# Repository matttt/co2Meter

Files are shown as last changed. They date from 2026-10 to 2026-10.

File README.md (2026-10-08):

# ESP32-C6 eInk CO2 meter

IMG_9852 Medium

IMG_9853 Medium

CleanShot 2026-10-07 at 20 32 52

built with:
- [ESP32-C6 Feather, product 5933](https://www.adafruit.com/product/5933)
- [2.13-inch 250x122 monochrome eInk breakout, product 4197](https://www.adafruit.com/product/4197)
- [SCD-40 CO2, temperature, and humidity sensor, product 5187](https://www.adafruit.com/product/5187)
- Small lipo battery ~1000mAH, ~20x40mm in the major dimensions
- some M2 heat set inserts and M2 x 6mm socket head screws

The following is LLM generated, apologies for the verbosity, but there's some useful stuff:

At boot and after each wake, the firmware starts the SCD-40's low-power
periodic mode, reads one valid sample after about 30 seconds, stops measurement,
and renders the dashboard. The ESP32 then deep sleeps for one hour and repeats.
There is no five-minute sampling or averaging. The eInk image remains visible
while asleep; flashing during its several-second refresh is normal.

Solder the supplied header onto the eInk breakout before making these jumper
connections.

## Wiring

Use the breakout's header pins. The first column uses labels printed on the
Feather; the GPIO column is included to remove any ambiguity.

| ESP32-C6 Feather | GPIO | eInk breakout |
| --- | ---: | --- |
| `3V` | - | `VIN` / `3-5V` |
| `GND` | - | `GND` |
| `SCK` | 21 | `SCK` / `CLK` |
| `MO` / `MOSI` | 22 | `MOSI` |
| `MI` / `MISO` | 23 | `MISO` |
| `0` / `SS` | 0 | `ECS` |
| `A0` | 1 | `D/C` |
| `A5` | 2 | `SRCS` |
| `A4` | 3 | `RST` |
| `A2` | 6 | `ENA` |
| `7` | 7 | `BUSY` |
| `TX` | 16 | `SDCS` |

Leave the display's `3.3V out` pin disconnected. Be careful to use the
display's `VIN` input, not its `3.3V out` regulator output, for power.

This mapping uses the Feather's hardware SPI pins; avoids the C6 strapping,
USB-JTAG, boot/NeoPixel, and LED pins; and leaves I2C/STEMMA QT available for
the SCD-40. GPIO 16 is reserved for SD chip select, so it is no longer available
as hardware UART TX.

## SCD-40 connection

The easiest connection is a STEMMA QT cable between the Feather and SCD-40. No
additional display pins are shared. For individual wires, use:

| SCD-40 | ESP32-C6 Feather | GPIO |
| --- | --- | ---: |
| `VIN` | `3V` | - |
| `GND` | `GND` | - |
| `SCL` | `SCL` | 18 |
| `SDA` | `SDA` | 19 |

The firmware displays temperature in Fahrenheit by default. Set
`kUseFahrenheit` to `false` in `src/main.cpp` to display Celsius.

## Battery warnings

The Feather's onboard MAX17048 fuel gauge shares I2C with the SCD-40; no extra
wiring is required. The firmware checks it on each wake, while waiting for a
sensor sample, and before displaying a reading or sensor error. At **20% or
less**, a small low-battery icon appears in the top-left corner of the dashboard
and sensor-error screen.

At **5% or less**, or a cell voltage of **3.4 V or less**, the dashboard is
replaced by a full-screen empty-battery icon, **LOW BATTERY**, and **PLEASE
RECHARGE**. The firmware skips sensor measurements and deep sleeps, checking
again at the next wake so readings resume after recharging. This reserves charge
for the final refresh: eInk retains the warning after power is lost, but cannot
draw a new image once power has already cut out, including during sleep.

Tune `kLowBatteryPercent`, `kDepletedBatteryPercent`, and
`kDepletedBatteryVoltage` in `src/main.cpp` for your battery. Missing batteries
and failed gauge reads do not count as depletion; the firmware retains the last
valid state for that wake, or starts without a warning when none is available.
The gauge is read without resetting its charge estimate on each wake.

## Deep sleep and interval tuning

Set `kSleepIntervalMinutes` near the top of `src/main.cpp`: `60` for one hour,
`120` for two hours. This is the sleep duration **after** each refresh, so the
interval between displayed readings also includes measurement and refresh time.
For a quick hardware check, temporarily set it to `1`.

The SCD-40 uses a start/read/stop sequence because it does not support true
single-shot CO2 measurement. Before host sleep, the firmware releases I2C and
its internal pull-ups, then drives GPIO20 (`PIN_NEOPIXEL_I2C_POWER`) low and
holds it there. This switches off the STEMMA QT supply, including the SCD-40
and its green power LED, without extra wiring. On wake, power is restored and
the firmware waits one second before initializing the sensor. This also powers
off any other devices on that STEMMA supply and the onboard NeoPixel.

This power switching requires the sensor to be powered through STEMMA QT;
a sensor wired directly to the Feather's `3V` pin stays powered.
See [Adafruit's low-power guide](https://learn.adafruit.com/adafruit-esp32-c6-feather/low-power-use).

A failed initialization or a measurement that produces no valid reading within
45 seconds displays a sensor error and sleeps before retrying next wake.

The display library sleeps the panel controller after refreshing. The firmware
holds `ENA` high during ESP32 deep sleep to keep the display/SRAM rail powered
and avoid back-powering it through control pins. It also retains SD deselection. This is ESP32 deep sleep, not a complete peripheral power
shutdown; total board current still needs to be measured on hardware.

## BOOT button programming mode

**Add a jumper from Feather `IO9` to `A3` (GPIO 5).** BOOT is connected to GPIO 9,
which cannot wake the ESP32-C6 from deep sleep. GPIO 5 is an unused wake-capable
input; the jumper lets the same button drive it. Both pins are configured as
inputs with pull-ups. Do not drive the onboard NeoPixel while using this jumper,
since it shares GPIO 9.

Press BOOT to wake immediately, and keep holding for ten seconds after firmware
starts to enter programming mode. The screen displays **PROGRAMMING MODE**, and
the firmware stays awake indefinitely for uploading. Release BOOT once that
message appears. Tap RESET with BOOT released to resume normal operation.
A shorter press wakes the meter for a normal reading and starts a new sleep
interval. Holding BOOT while already awake also enters programming mode.

Without the jumper, BOOT can enter programming mode only while the firmware is
already awake. To access it while sleeping, tap RESET first, then press and hold
BOOT once firmware starts. Holding BOOT *during reset* selects the ROM bootloader
instead; that remains an alternative recovery/upload path but cannot render the
programming-mode screen.

The ten-second hold is checked in firmware after wake, since the hardware wake
source triggers on a low level rather than timing the press. Allow additional
time for startup and the eInk refresh before the message appears. Programming
mode lasts until reset or power cycling; it is not saved in flash.

The microSD card shares `SCK`, `MOSI`, and `MISO` with the display and SRAM. Its
separate `SDCS` connection uses `TX` / GPIO 16. Until SD support is added, the
firmware holds this pin high to keep the card deselected. USB serial remains
available, but GPIO 16 should no longer be used as a hardware UART TX pin.

## Build and upload

From this directory:

```sh
pio run
pio run --target upload
pio device monitor
```

The serial monitor runs at 115200 baud. If PlatformIO cannot enter the ROM
bootloader automatically, hold **BOOT**, tap **RESET**, release **BOOT**, and run
the upload command again.

## Display revision

This particular display's ribbon is marked `FPC-7528B`, so the firmware uses
the `ThinkInk_213_Mono_BN` SSD1680 driver. Its framebuffer needs an 8-pixel
memory offset; using `ThinkInk_213_Mono_GDEY0213B74` causes a shifted image and
a noisy strip along one edge.

For a different panel, select its driver by its physical marking:

- `GDEY0213B74` / `FPC-A002`: use `ThinkInk_213_Mono_GDEY0213B74`.
- Very old SSD1675 product 4197 units: use `ThinkInk_213_Mono_B72`. The SSD1675
  and SSD1680 are not code-compatible.

Adafruit references:

- [eInk breakout pinout](https://learn.adafruit.com/adafruit-2-13-eink-display-breakouts-and-featherwings/pinouts)
- [ESP32-C6 Feather pinout](https://learn.adafruit.com/adafruit-esp32-c6-feather/pinouts)
- [Adafruit EPD Arduino library](https://github.com/adafruit/Adafruit_EPD)
- [Adafruit SCD-4x Arduino guide](https://learn.adafruit.com/adafruit-scd-40-and-scd-41/arduino)
- [Sensirion SCD4x Arduino library](https://github.com/Sensirion/arduino-i2c-scd4x)

## Hardware verification

- With a one-minute test interval, confirm one reading after about 30 seconds,
  followed by a sleep log, USB disconnect, timer wake, and a fresh reading.
  Confirm the SCD-40 green LED is off throughout sleep and lights again on wake.
- With IO9 jumpered to A3, hold BOOT during sleep until PROGRAMMING MODE appears.
  Release it, wait longer than the test interval, and confirm USB remains usable
  and the screen remains in programming mode. Upload, or RESET to resume.
- Try a short BOOT press during sleep: it should take a normal reading and sleep.
- Disconnect the sensor: confirm the error screen and a subsequent sleep/retry.
- Check with a low battery: confirm the corner icon at 20% or less. At 5% or
  less or 3.4 V or less, confirm the full-screen warning and sleep without an
  SCD-40 measurement. Recharge and wake/reset to confirm readings resume. For a
  quick screen check, temporarily raise the percentage thresholds above the
  charge reported in the serial log, then restore them before normal use.
- With only USB power and no battery, confirm the dashboard still renders.
- Restore the intended interval before the final upload.

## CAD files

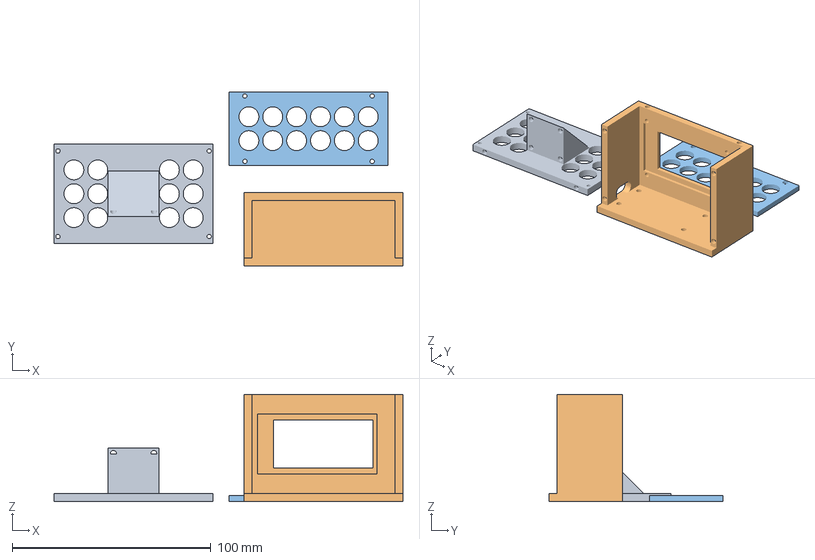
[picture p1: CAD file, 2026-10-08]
3dPrintFiles/co2 case.3mf
175.5 x 87.4 x 54.0 mm
back panel.obj
bodyody.obj
top.obj

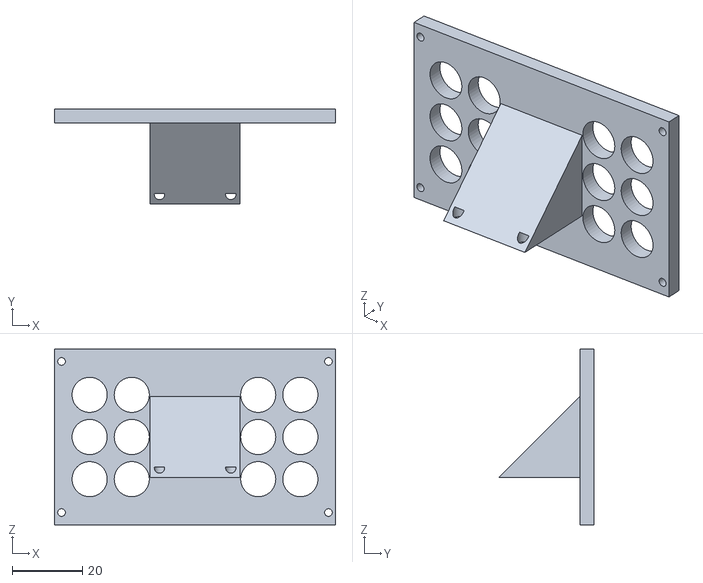
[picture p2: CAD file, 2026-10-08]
3dPrintFiles/back panel.obj
80.0 x 27.0 x 50.0

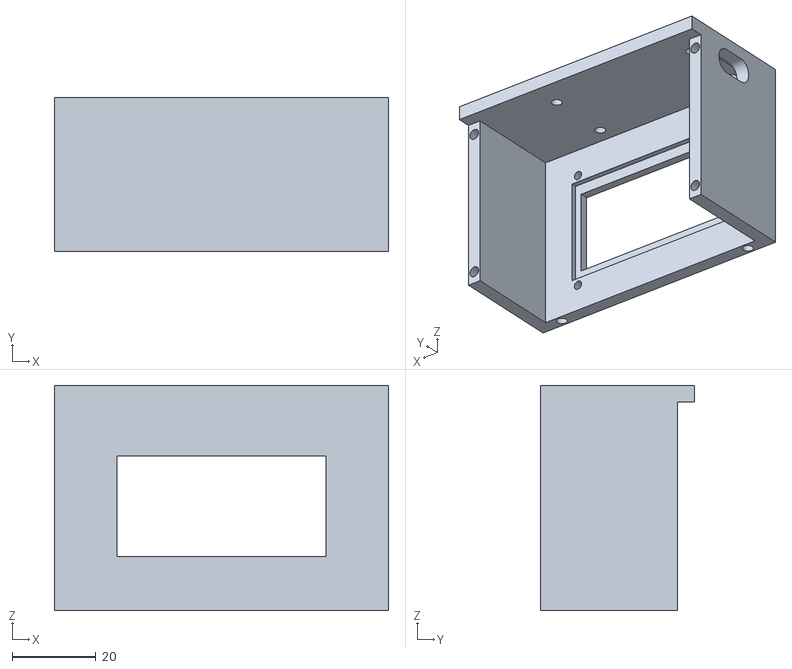
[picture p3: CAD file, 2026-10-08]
3dPrintFiles/bodyody.obj
80.0 x 36.9 x 54.0

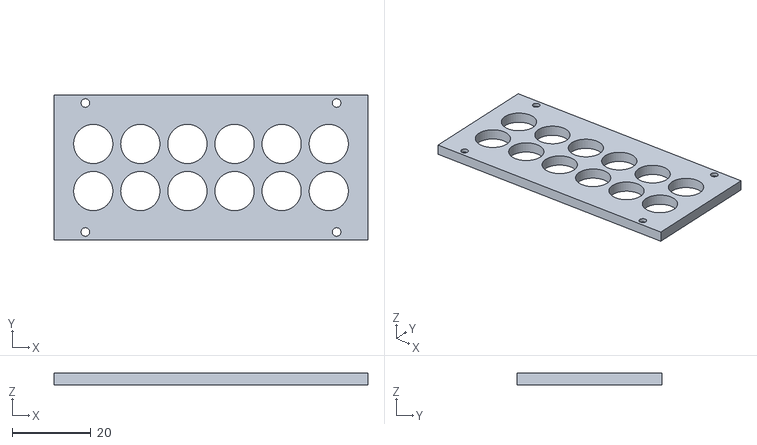
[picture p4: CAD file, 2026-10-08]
3dPrintFiles/top.obj
80.0 x 36.9 x 3.00

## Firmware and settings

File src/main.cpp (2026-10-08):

#include <Arduino.h>
#include <Adafruit_ThinkInk.h>
#include <Fonts/FreeSansBold24pt7b.h>
#include <Fonts/FreeSansBold9pt7b.h>
#include <SensirionI2cScd4x.h>
#include <Wire.h>
#include <driver/gpio.h>
#include <esp_sleep.h>

namespace {

// Adafruit ESP32-C6 Feather -> Adafruit 2.13" eInk breakout wiring.
// The display, SRAM, and microSD card share the Feather's hardware SPI bus.
constexpr int8_t kEpdCs = SS;      // GPIO 0 -> ECS
constexpr int8_t kEpdDc = A0;      // GPIO 1 -> D/C
constexpr int8_t kSramCs = A5;     // GPIO 2 -> SRCS
constexpr int8_t kEpdReset = A4;   // GPIO 3 -> RST
constexpr int8_t kEpdBusy = 7;     // GPIO 7 -> BUSY
constexpr int8_t kEpdEnable = A2;  // GPIO 6 -> ENA (HIGH = powered)
constexpr int8_t kSdCs = TX;       // GPIO 16 -> SDCS (LOW = selected)

// Sleep duration AFTER each measurement and display refresh. Change to 120
// for two hours; use a short interval when testing on hardware.
constexpr uint32_t kSleepIntervalMinutes = 60;
constexpr uint64_t kSleepIntervalUs =
    static_cast<uint64_t>(kSleepIntervalMinutes) * 60ULL * 1000000ULL;
constexpr uint32_t kSensorPollIntervalMs = 1000;
constexpr uint32_t kMeasurementTimeoutMs = 45UL * 1000UL;
constexpr uint32_t kDisplayPowerUpDelayMs = 100;
constexpr uint32_t kSensorPowerUpDelayMs = 1000;
constexpr uint32_t kProgrammingHoldMs = 10UL * 1000UL;
constexpr int8_t kBootButton = 9;
// REQUIRED jumper: IO9 -> A3. GPIO9 cannot wake the C6 from deep sleep.
constexpr gpio_num_t kWakeButton = GPIO_NUM_5;
constexpr int16_t kLayoutOffsetX = -4;
constexpr int16_t kSidebarContentOffsetX = 3;
constexpr bool kUseFahrenheit = true;
constexpr int16_t kNoError = 0;
// The onboard MAX17048 shares I2C with the SCD-40. Leave enough charge for a
// final eInk refresh before the battery or regulator cuts off power.
constexpr uint8_t kBatteryMonitorAddress = 0x36;
constexpr float kLowBatteryPercent = 20.0F;
constexpr float kDepletedBatteryPercent = 5.0F;
constexpr float kDepletedBatteryVoltage = 3.4F;

static_assert(kSleepIntervalMinutes > 0);
static_assert(kDepletedBatteryPercent < kLowBatteryPercent);

// This display is marked FPC-7528B. Its SSD1680 framebuffer needs the BN/B74
// memory offset; using the GDEY0213B74 driver leaves a noisy 8-pixel strip.
ThinkInk_213_Mono_BN display(kEpdDc, kEpdReset, kEpdCs, kSramCs, kEpdBusy,
                             &SPI);
SensirionI2cScd4x scd40;

struct AirReading {
  uint16_t co2Ppm;
  float temperatureC;
  float humidityPercent;
};

enum class BatteryState { Unknown, Normal, Low, Depleted };

BatteryState batteryState = BatteryState::Unknown;
bool sensorAvailable = false;
bool measurementRunning = false;
bool programmingMode = false;
uint32_t lastSensorPollMs = 0;
uint32_t measurementStartedMs = 0;

bool readBatteryRegister(uint8_t address, uint16_t& value) {
  Wire.beginTransmission(kBatteryMonitorAddress);
  Wire.write(address);
  if (Wire.endTransmission(false) != 0) {
    return false;
  }
  if (Wire.requestFrom(kBatteryMonitorAddress, static_cast<size_t>(2)) != 2) {
    return false;
  }
  value = static_cast<uint16_t>(Wire.read()) << 8;
  value |= static_cast<uint16_t>(Wire.read());
  return true;
}

void updateBatteryStatus(bool logReading = false) {
  uint16_t version = 0;
  uint16_t rawVoltage = 0;
  uint16_t rawPercent = 0;
  // Read without resetting/quick-starting the gauge on each deep-sleep wake;
  // its state-of-charge estimate must continue tracking while the ESP32 sleeps.
  // An absent battery or I2C failure must not be mistaken for an empty battery.
  if (!readBatteryRegister(0x08, version) ||
      (version & 0xFFF0) != 0x0010 ||
      !readBatteryRegister(0x02, rawVoltage) ||
      !readBatteryRegister(0x04, rawPercent) || rawVoltage == 0 ||
      rawPercent == 0xFFFF) {
    if (logReading) {
      Serial.println("Battery reading unavailable; retaining last known state.");
    }
    return;
  }

  // MAX17048 VCELL is 78.125 uV/LSB; SOC is 1/256 percent/LSB.
  const float voltage = rawVoltage * 0.000078125F;
  const float percent = min(rawPercent / 256.0F, 100.0F);
  if (voltage > 4.5F) {
    return;
  }
  if (percent <= kDepletedBatteryPercent ||
      voltage <= kDepletedBatteryVoltage) {
    batteryState = BatteryState::Depleted;
  } else if (percent <= kLowBatteryPercent) {
    batteryState = BatteryState::Low;
  } else {
    batteryState = BatteryState::Normal;
  }
  if (logReading) {
    Serial.printf("Battery: %.1f%%, %.3f V\n", percent, voltage);
  }
}

void printSensorError(const char* operation, int16_t error) {
  char message[64] = {};
  errorToString(error, message, sizeof(message));
  Serial.printf("SCD-40 %s failed: %s (error %d)\n", operation, message,
                error);
}

void initializeDisplay() {
  // Keep the breakout rail powered; display.display() puts the panel controller
  // into sleep after refreshing. Reinitialize after each ESP32 deep-sleep wake.
  pinMode(kEpdEnable, OUTPUT);
  digitalWrite(kEpdEnable, HIGH);
  delay(kDisplayPowerUpDelayMs);

  display.begin(THINKINK_MONO);
  display.setRotation(2);
  display.setTextColor(EPD_BLACK);
  display.setTextWrap(false);
}

void finishDisplayUpdate() {
  Serial.println("Refreshing eInk display...");
  const uint32_t refreshStartedMs = millis();
  display.display();
  Serial.printf("eInk refresh complete in %lu ms; panel controller asleep.\n",
                static_cast<unsigned long>(millis() - refreshStartedMs));
}

void drawCenteredText(const char* text, int16_t centerX, int16_t baselineY,
                      const GFXfont* font) {
  int16_t x1 = 0;
  int16_t y1 = 0;
  uint16_t width = 0;
  uint16_t height = 0;

  display.setFont(font);
  display.getTextBounds(text, 0, baselineY, &x1, &y1, &width, &height);
  display.setCursor(centerX - static_cast<int16_t>(width) / 2 - x1,
                    baselineY);
  display.print(text);
}

void drawBatteryIcon(int16_t x, int16_t y, uint8_t scale, bool empty) {
  display.drawRect(x, y, 20 * scale, 12 * scale, EPD_BLACK);
  display.drawRect(x + scale, y + scale, 18 * scale, 10 * scale,
                   EPD_BLACK);
  display.fillRect(x + 20 * scale, y + 4 * scale, 2 * scale, 4 * scale,
                   EPD_BLACK);
  if (!empty) {
    display.fillRect(x + 3 * scale, y + 3 * scale, 3 * scale, 6 * scale,
                     EPD_BLACK);
  }
}

void drawLowBatteryWarning() {
  if (batteryState == BatteryState::Low) {
    drawBatteryIcon(4, 4, 1, false);
  }
}

void showDepletedBattery() {
  display.clearBuffer();
  display.setTextSize(1);
  const int16_t centerX = display.width() / 2 + kLayoutOffsetX;
  drawBatteryIcon(centerX - 33, 18, 3, true);
  drawCenteredText("LOW BATTERY", centerX, 80, &FreeSansBold9pt7b);
  drawCenteredText("PLEASE RECHARGE", centerX, 104, nullptr);
  finishDisplayUpdate();
}

void drawCo2Value(uint16_t co2Ppm) {
  char value[8] = {};
  snprintf(value, sizeof(value), "%u", co2Ppm);

  // A three-digit value uses the 24pt font at 2x scale. Step down to its native
  // size at four digits so both cases remain large without touching the rule.
  constexpr GFXfont const* kValueFont = &FreeSansBold24pt7b;
  const uint8_t valueScale = co2Ppm < 1000 ? 2 : 1;

  int16_t valueX1 = 0;
  int16_t valueY1 = 0;
  int16_t ppmX1 = 0;
  int16_t ppmY1 = 0;
  int16_t co2X1 = 0;
  int16_t co2Y1 = 0;
  uint16_t valueWidth = 0;
  uint16_t valueHeight = 0;
  uint16_t ppmWidth = 0;
  uint16_t ppmHeight = 0;
  uint16_t co2Width = 0;
  uint16_t co2Height = 0;

  display.setFont(kValueFont);
  display.setTextSize(valueScale);
  display.getTextBounds(value, 0, 0, &valueX1, &valueY1, &valueWidth,
                        &valueHeight);
  display.setFont(nullptr);
  display.setTextSize(1);
  display.getTextBounds("PPM", 0, 0, &ppmX1, &ppmY1, &ppmWidth, &ppmHeight);
  display.getTextBounds("CO2", 0, 0, &co2X1, &co2Y1, &co2Width, &co2Height);

  constexpr int16_t kLabelGap = 7;
  const int16_t sidebarLeft =
      display.width() * 3 / 4 + kLayoutOffsetX;
  const int16_t co2AreaCenterX = (kLayoutOffsetX + sidebarLeft) / 2;
  const int16_t labelsWidth =
      max(static_cast<int16_t>(ppmWidth), static_cast<int16_t>(co2Width));
  const int16_t groupWidth =
      static_cast<int16_t>(valueWidth) + kLabelGap + labelsWidth;
  const int16_t valueLeft = co2AreaCenterX - groupWidth / 2;
  const int16_t labelsLeft =
      valueLeft + static_cast<int16_t>(valueWidth) + kLabelGap;

  // Center the number vertically, then center the stacked labels against the
  // number's visible glyph bounds instead of its font baseline.
  const int16_t valueTop =
      (display.height() - static_cast<int16_t>(valueHeight)) / 2;
  const int16_t valueBaselineY = valueTop - valueY1;
  constexpr int16_t kLabelRowGap = 2;
  const int16_t labelsHeight = static_cast<int16_t>(ppmHeight) +
                               kLabelRowGap +
                               static_cast<int16_t>(co2Height);
  const int16_t labelsTop =
      valueTop + (static_cast<int16_t>(valueHeight) - labelsHeight) / 2;
  const int16_t ppmTop = labelsTop - ppmY1;
  const int16_t co2Top = labelsTop + static_cast<int16_t>(ppmHeight) +
                         kLabelRowGap - co2Y1;

  display.setFont(kValueFont);
  display.setTextSize(valueScale);
  display.setCursor(valueLeft - valueX1, valueBaselineY);
  display.print(value);

  display.setFont(nullptr);
  display.setTextSize(1);
  display.setCursor(labelsLeft - ppmX1, ppmTop);
  display.print("PPM");
  display.setCursor(labelsLeft - co2X1, co2Top);
  display.print("CO2");
}

void drawMetric(int16_t centerX, int16_t boxTop, int16_t boxBottom,
                const char* label, const char* value) {
  int16_t labelX1 = 0;
  int16_t labelY1 = 0;
  int16_t valueX1 = 0;
  int16_t valueY1 = 0;
  uint16_t labelWidth = 0;
  uint16_t labelHeight = 0;
  uint16_t valueWidth = 0;
  uint16_t valueHeight = 0;

  display.setFont(nullptr);
  display.setTextSize(1);
  display.getTextBounds(label, 0, 0, &labelX1, &labelY1, &labelWidth,
                        &labelHeight);
  display.setFont(&FreeSansBold9pt7b);
  display.getTextBounds(value, 0, 0, &valueX1, &valueY1, &valueWidth,
                        &valueHeight);

  constexpr int16_t kLabelValueGap = 10;
  const int16_t groupHeight = static_cast<int16_t>(labelHeight) +
                              kLabelValueGap +
                              static_cast<int16_t>(valueHeight);
  const int16_t groupTop =
      boxTop + (boxBottom - boxTop + 1 - groupHeight) / 2;
  const int16_t valueTop =
      groupTop + static_cast<int16_t>(labelHeight) + kLabelValueGap;

  display.setFont(nullptr);
  display.setTextSize(1);
  display.setCursor(centerX - static_cast<int16_t>(labelWidth) / 2 - labelX1,
                    groupTop - labelY1);
  display.print(label);

  display.setFont(&FreeSansBold9pt7b);
  display.setCursor(centerX - static_cast<int16_t>(valueWidth) / 2 - valueX1,
                    valueTop - valueY1);
  display.print(value);
}

void drawDashboard(const AirReading& reading) {
  char temperature[16] = {};
  char humidity[16] = {};

  const float shownTemperature =
      kUseFahrenheit ? reading.temperatureC * 1.8F + 32.0F
                     : reading.temperatureC;
  snprintf(temperature, sizeof(temperature), "%.1f %c", shownTemperature,
           kUseFahrenheit ? 'F' : 'C');
  snprintf(humidity, sizeof(humidity), "%.0f%%", reading.humidityPercent);

  display.clearBuffer();

  drawCo2Value(reading.co2Ppm);

  const int16_t sidebarLeft =
      display.width() * 3 / 4 + kLayoutOffsetX;
  const int16_t contentRight = display.width() + kLayoutOffsetX;
  const int16_t sidebarCenterX =
      (sidebarLeft + contentRight) / 2 + kSidebarContentOffsetX;
  const int16_t middleY = display.height() / 2;

  display.drawFastVLine(sidebarLeft, 4, display.height() - 8, EPD_BLACK);
  display.drawFastHLine(sidebarLeft, middleY, display.width() - sidebarLeft,
                        EPD_BLACK);

  drawMetric(sidebarCenterX, 4, middleY - 1, "TEMP", temperature);
  drawMetric(sidebarCenterX, middleY + 1, display.height() - 5, "HUMIDITY",
             humidity);
  drawLowBatteryWarning();
}

void showSensorError() {
  updateBatteryStatus(true);
  if (batteryState == BatteryState::Depleted) {
    showDepletedBattery();
    return;
  }
  display.clearBuffer();
  display.setTextSize(1);
  drawCenteredText("SCD-40", display.width() / 2 + kLayoutOffsetX, 35,
                   &FreeSansBold9pt7b);
  drawCenteredText("SENSOR ERROR", display.width() / 2 + kLayoutOffsetX, 67,
                   &FreeSansBold9pt7b);
  drawCenteredText("CHECK STEMMA QT", display.width() / 2 + kLayoutOffsetX,
                   96, nullptr);
  drawLowBatteryWarning();
  finishDisplayUpdate();
}

void showReading(const AirReading& reading) {
  updateBatteryStatus(true);
  if (batteryState == BatteryState::Depleted) {
    showDepletedBattery();
    return;
  }
  drawDashboard(reading);
  finishDisplayUpdate();
}

bool initializeSensor() {
  scd40.begin(Wire, SCD40_I2C_ADDR_62);
  delay(30);

  // A microcontroller reset does not reset a separately powered SCD-40. Stop
  // any measurement left running by the previous boot before reinitializing.
  int16_t error = scd40.stopPeriodicMeasurement();
  if (error != kNoError) {
    printSensorError("stopPeriodicMeasurement", error);
    return false;
  }

  error = scd40.reinit();
  if (error != kNoError) {
    printSensorError("reinit", error);
    return false;
  }

  uint64_t serialNumber = 0;
  error = scd40.getSerialNumber(serialNumber);
  if (error != kNoError) {
    printSensorError("getSerialNumber", error);
    return false;
  }

  Serial.printf("SCD-40 detected, serial 0x%04X%08X\n",
                static_cast<uint16_t>(serialNumber >> 32),
                static_cast<uint32_t>(serialNumber));

  return true;
}

bool startMeasurementCycle() {
  const int16_t error = scd40.startLowPowerPeriodicMeasurement();
  if (error != kNoError) {
    printSensorError("startLowPowerPeriodicMeasurement", error);
    return false;
  }

  measurementRunning = true;
  measurementStartedMs = millis();
  lastSensorPollMs = measurementStartedMs;
  Serial.println("SCD-40 measurement started; waiting about 30 seconds...");
  return true;
}

bool stopMeasurementCycle() {
  const int16_t error = scd40.stopPeriodicMeasurement();
  if (error != kNoError) {
    printSensorError("stopPeriodicMeasurement", error);
    return false;
  }

  measurementRunning = false;
  return true;
}

bool readSensor(AirReading& reading) {
  bool dataReady = false;
  int16_t error = scd40.getDataReadyStatus(dataReady);
  if (error != kNoError) {
    printSensorError("getDataReadyStatus", error);
    return false;
  }

  if (!dataReady) {
    return false;
  }

  error = scd40.readMeasurement(reading.co2Ppm, reading.temperatureC,
                                reading.humidityPercent);
  if (error != kNoError) {
    printSensorError("readMeasurement", error);
    return false;
  }

  if (reading.co2Ppm == 0) {
    Serial.println("SCD-40 returned an invalid zero-ppm sample; ignoring it.");
    return false;
  }

  Serial.printf("CO2: %u ppm, temperature: %.2f C, humidity: %.2f %%RH\n",
                reading.co2Ppm, reading.temperatureC,
                reading.humidityPercent);
  return true;
}

// A held button delays all other work so sleep cannot interrupt the gesture.
// Called before sensor initialization, while measuring, and before sleeping.
bool checkProgrammingButton() {
  if (programmingMode) {
    return true;
  }
  if (digitalRead(kBootButton) != LOW) {
    return false;
  }

  const uint32_t pressedMs = millis();
  while (digitalRead(kBootButton) == LOW) {
    if (millis() - pressedMs >= kProgrammingHoldMs) {
      programmingMode = true;
      if (measurementRunning) {
        stopMeasurementCycle();
      }
      display.clearBuffer();
      display.setTextSize(1);
      drawCenteredText("PROGRAMMING", display.width() / 2, 42,
                       &FreeSansBold9pt7b);
      drawCenteredText("MODE", display.width() / 2, 67,
                       &FreeSansBold9pt7b);
      drawCenteredText("RESET TO RESUME", display.width() / 2, 96, nullptr);
      drawLowBatteryWarning();
      finishDisplayUpdate();
      Serial.println("Programming mode: deep sleep disabled until reset.");
      return true;
    }
    delay(10);
  }
  return false;
}

void sleepUntilNextReading() {
  if (checkProgrammingButton()) {
    return;
  }
  // Retry stopping after a sensor fault before putting the host to sleep.
  if (measurementRunning) {
    stopMeasurementCycle();
  }
  ESP_ERROR_CHECK(esp_sleep_enable_timer_wakeup(kSleepIntervalUs));
  ESP_ERROR_CHECK(esp_deep_sleep_enable_gpio_wakeup(
      1ULL << kWakeButton, ESP_GPIO_WAKEUP_GPIO_LOW));

  // Release I2C and its internal pull-ups before removing STEMMA QT power.
  // Retain the high-impedance pins so the host cannot feed the unpowered sensor.
  Wire.end();
  pinMode(SDA, INPUT);
  pinMode(SCL, INPUT);
  ESP_ERROR_CHECK(gpio_hold_en(static_cast<gpio_num_t>(SDA)));
  ESP_ERROR_CHECK(gpio_hold_en(static_cast<gpio_num_t>(SCL)));
  digitalWrite(PIN_NEOPIXEL_I2C_POWER, LOW);

  // Retain STEMMA power OFF, display power ON, and SD deselection during sleep.
  // Keeping the display powered avoids back-powering it through SPI/control pins.
  ESP_ERROR_CHECK(gpio_hold_en(static_cast<gpio_num_t>(kEpdEnable)));
  ESP_ERROR_CHECK(gpio_hold_en(static_cast<gpio_num_t>(kSdCs)));
  ESP_ERROR_CHECK(gpio_hold_en(
      static_cast<gpio_num_t>(PIN_NEOPIXEL_I2C_POWER)));
  // ESP32-C6 retains individual pad holds in deep sleep without a global hold.
  Serial.printf("Deep sleeping for %lu minutes. Hold BOOT for programming.\n",
                static_cast<unsigned long>(kSleepIntervalMinutes));
  Serial.flush();
  esp_deep_sleep_start();
}

}  // namespace

void setup() {
  Serial.begin(115200);
  pinMode(kBootButton, INPUT_PULLUP);
  pinMode(kWakeButton, INPUT_PULLUP);

  // Set output levels before releasing the holds from the previous sleep.
  pinMode(kSdCs, OUTPUT);
  digitalWrite(kSdCs, HIGH);
  pinMode(kEpdEnable, OUTPUT);
  digitalWrite(kEpdEnable, HIGH);
  pinMode(PIN_NEOPIXEL_I2C_POWER, OUTPUT);
  digitalWrite(PIN_NEOPIXEL_I2C_POWER, HIGH);
  gpio_hold_dis(static_cast<gpio_num_t>(kEpdEnable));
  gpio_hold_dis(static_cast<gpio_num_t>(kSdCs));
  gpio_hold_dis(static_cast<gpio_num_t>(PIN_NEOPIXEL_I2C_POWER));
  gpio_hold_dis(static_cast<gpio_num_t>(SDA));
  gpio_hold_dis(static_cast<gpio_num_t>(SCL));
  // Unlike a host-only reset, a timer wake now cold-starts the SCD-40.
  // Allow its supply and startup to settle before sending any I2C commands.
  delay(kSensorPowerUpDelayMs);

  initializeDisplay();
  if (checkProgrammingButton()) {
    return;
  }
  Wire.begin();
  updateBatteryStatus(true);
  if (batteryState == BatteryState::Depleted) {
    showDepletedBattery();
    sleepUntilNextReading();
    return;
  }
  sensorAvailable = initializeSensor();
  if (sensorAvailable) {
    sensorAvailable = startMeasurementCycle();
  }
  if (!sensorAvailable) {
    showSensorError();
    sleepUntilNextReading();
  }
}

void loop() {
  if (checkProgrammingButton()) {
    delay(10);
    return;
  }
  if (!sensorAvailable) {
    sleepUntilNextReading();
    return;
  }

  const uint32_t now = millis();
  if (now - measurementStartedMs >= kMeasurementTimeoutMs) {
    Serial.println("SCD-40 timed out waiting for a valid measurement.");
    showSensorError();
    sleepUntilNextReading();
    return;
  }
  if (now - lastSensorPollMs < kSensorPollIntervalMs) {
    delay(10);
    return;
  }
  lastSensorPollMs = now;

  updateBatteryStatus();
  if (batteryState == BatteryState::Depleted) {
    showDepletedBattery();
    sleepUntilNextReading();
    return;
  }

  AirReading reading = {};
  if (!readSensor(reading)) {
    return;
  }
  if (!stopMeasurementCycle()) {
    showSensorError();
    sleepUntilNextReading();
    return;
  }
  showReading(reading);
  sleepUntilNextReading();
}

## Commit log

2026-10-08 low battery warnings
2026-10-08 add cad
    [back panel.obj, bodyody.obj, co2 case.3mf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]
2026-10-08 Update README to remove redundant hardware details
    Removed redundant mention of M2 heat set inserts and screws.
2026-10-08 Update README with firmware operation details
    Added a section explaining the firmware operation of the SCD-40 sensor.
